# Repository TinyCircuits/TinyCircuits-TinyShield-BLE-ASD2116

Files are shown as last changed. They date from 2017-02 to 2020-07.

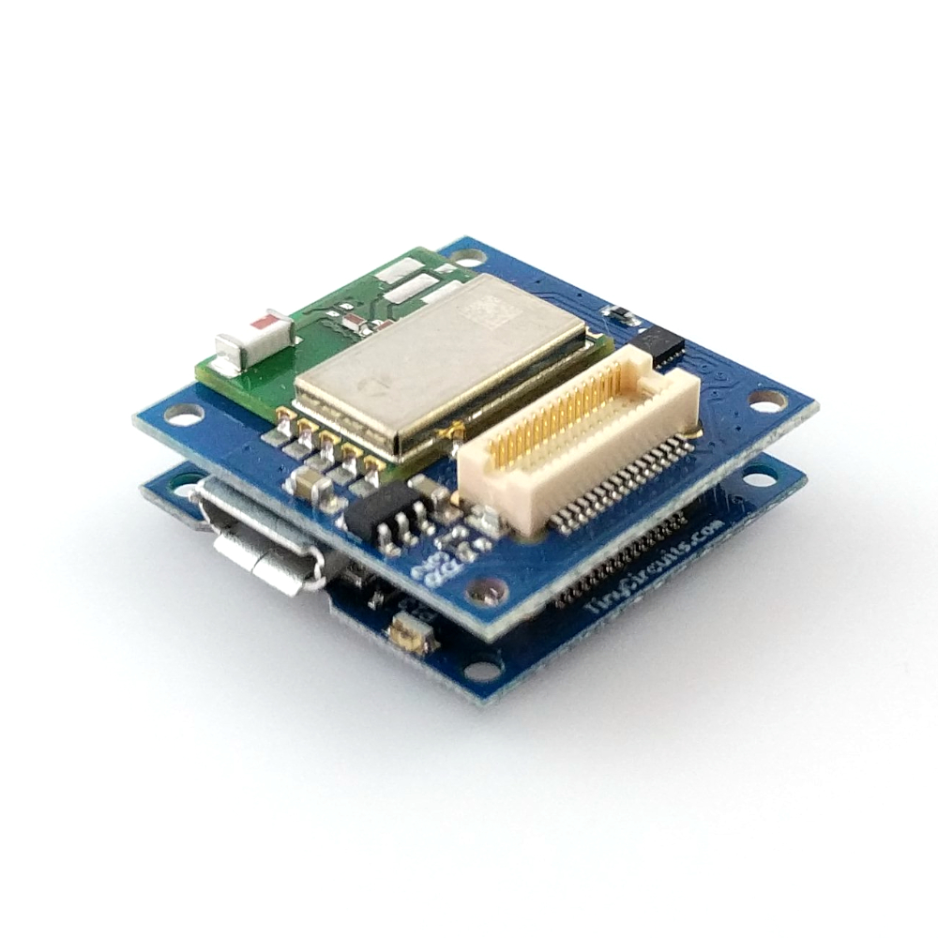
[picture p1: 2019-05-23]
images/ASD2116-R-Tutorial-Image-03.jpg

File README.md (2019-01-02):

# TinyCircuits Bluetooth Low Energy (BLE) TinyShield, ASD2116
# ASD2116 Rev2

The design files are located under design_files/ for the TinyCircuits ASD2116 Rev 2 PCB. This is a TinyShield board that has a BlueNRG-MS module, local power supply and level shifters to connect between the TinyDuino and BLE mod

Format is in Cadsoft Eagle format - Eagle version 6.3 was used for the original design.

For more information on this, check out the product page at TinyCircuits.com: https://tinycircuits.com/collections/communication/products/bluetooth-low-energy-tinyshield

# License

Design by TinyCircuits.
All design files are released under the Creative Commons Attribution Share-Alike 3.0 License, see the following link for details: http://creativecommons.org/licenses/by-sa/3.0

All text above must be included in any redistribution or derived design

This project uses designs and concepts developed as part of the Arduino project and the LilyPad project.  The TinyCircuits design files themselves (schematics, PCB and libraries) are not directly derived from these works' design files and have been created new, however the concepts and basic architecture behind the TinyDuino and TinyLily products are derived and we thank the hard work of the organizations below for their contributions to open-source hardware:
  
Original Arduino Uno Design by Team Arduino

LilyPad Arduino Design by Leah Buechley and Sparkfun Electronics

Please support the open-source hardware community

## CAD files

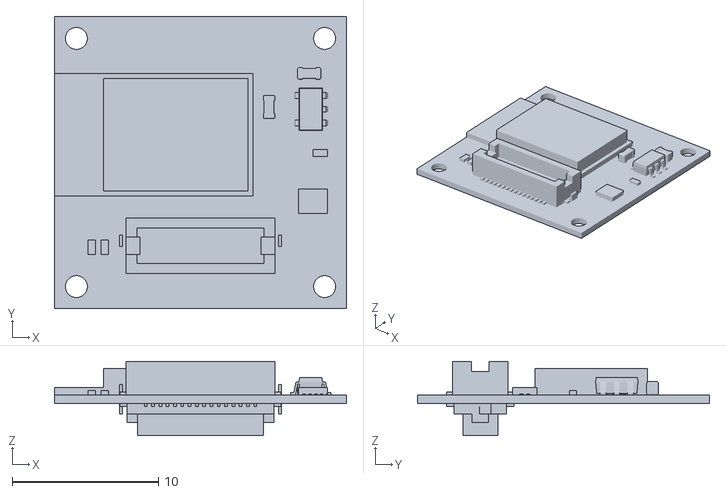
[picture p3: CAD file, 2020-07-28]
cad/TinyShield_STBLE_ASD2116_REV2-STL.stl
20.0 x 20.0 x 5.10

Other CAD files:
cad/TinyShield_STBLE_ASD2116_REV2-DETAILED_DRAWING-DXF.dxf

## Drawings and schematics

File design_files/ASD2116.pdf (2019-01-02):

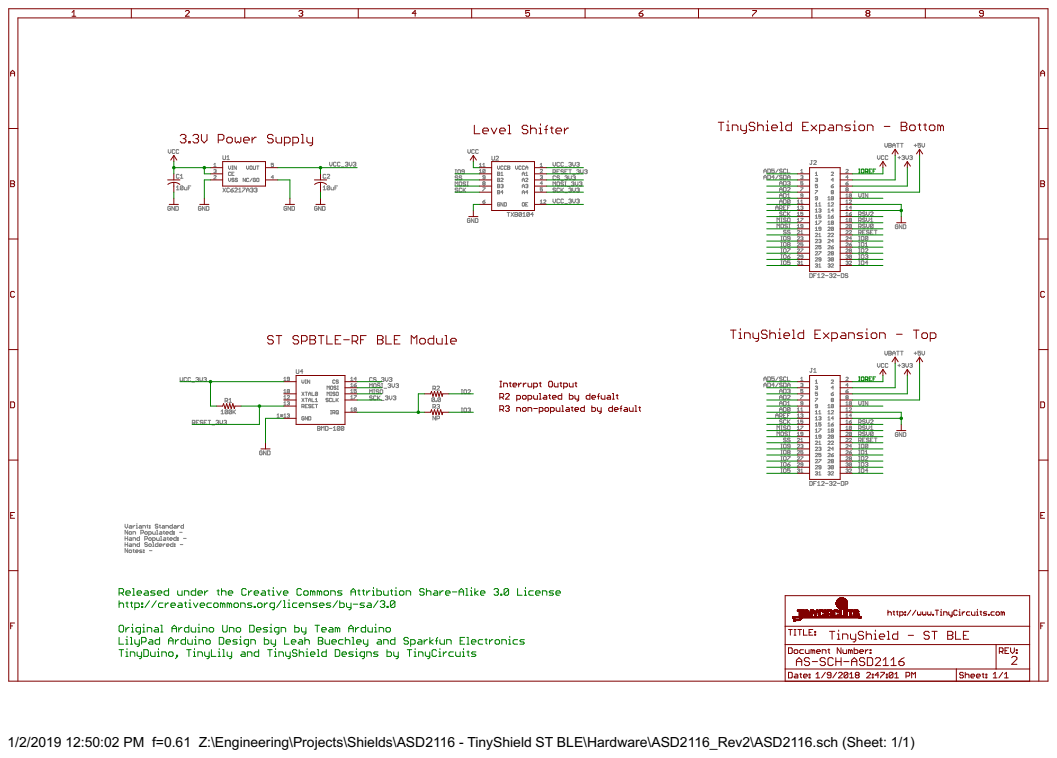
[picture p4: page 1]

1/2/2019 12:50:02 PM f=0.61 Z:\Engineering\Projects\Shields\ASD2116 - TinyShield ST BLE\Hardware\ASD2116_Rev2\ASD2116.sch (Sheet: 1/1)

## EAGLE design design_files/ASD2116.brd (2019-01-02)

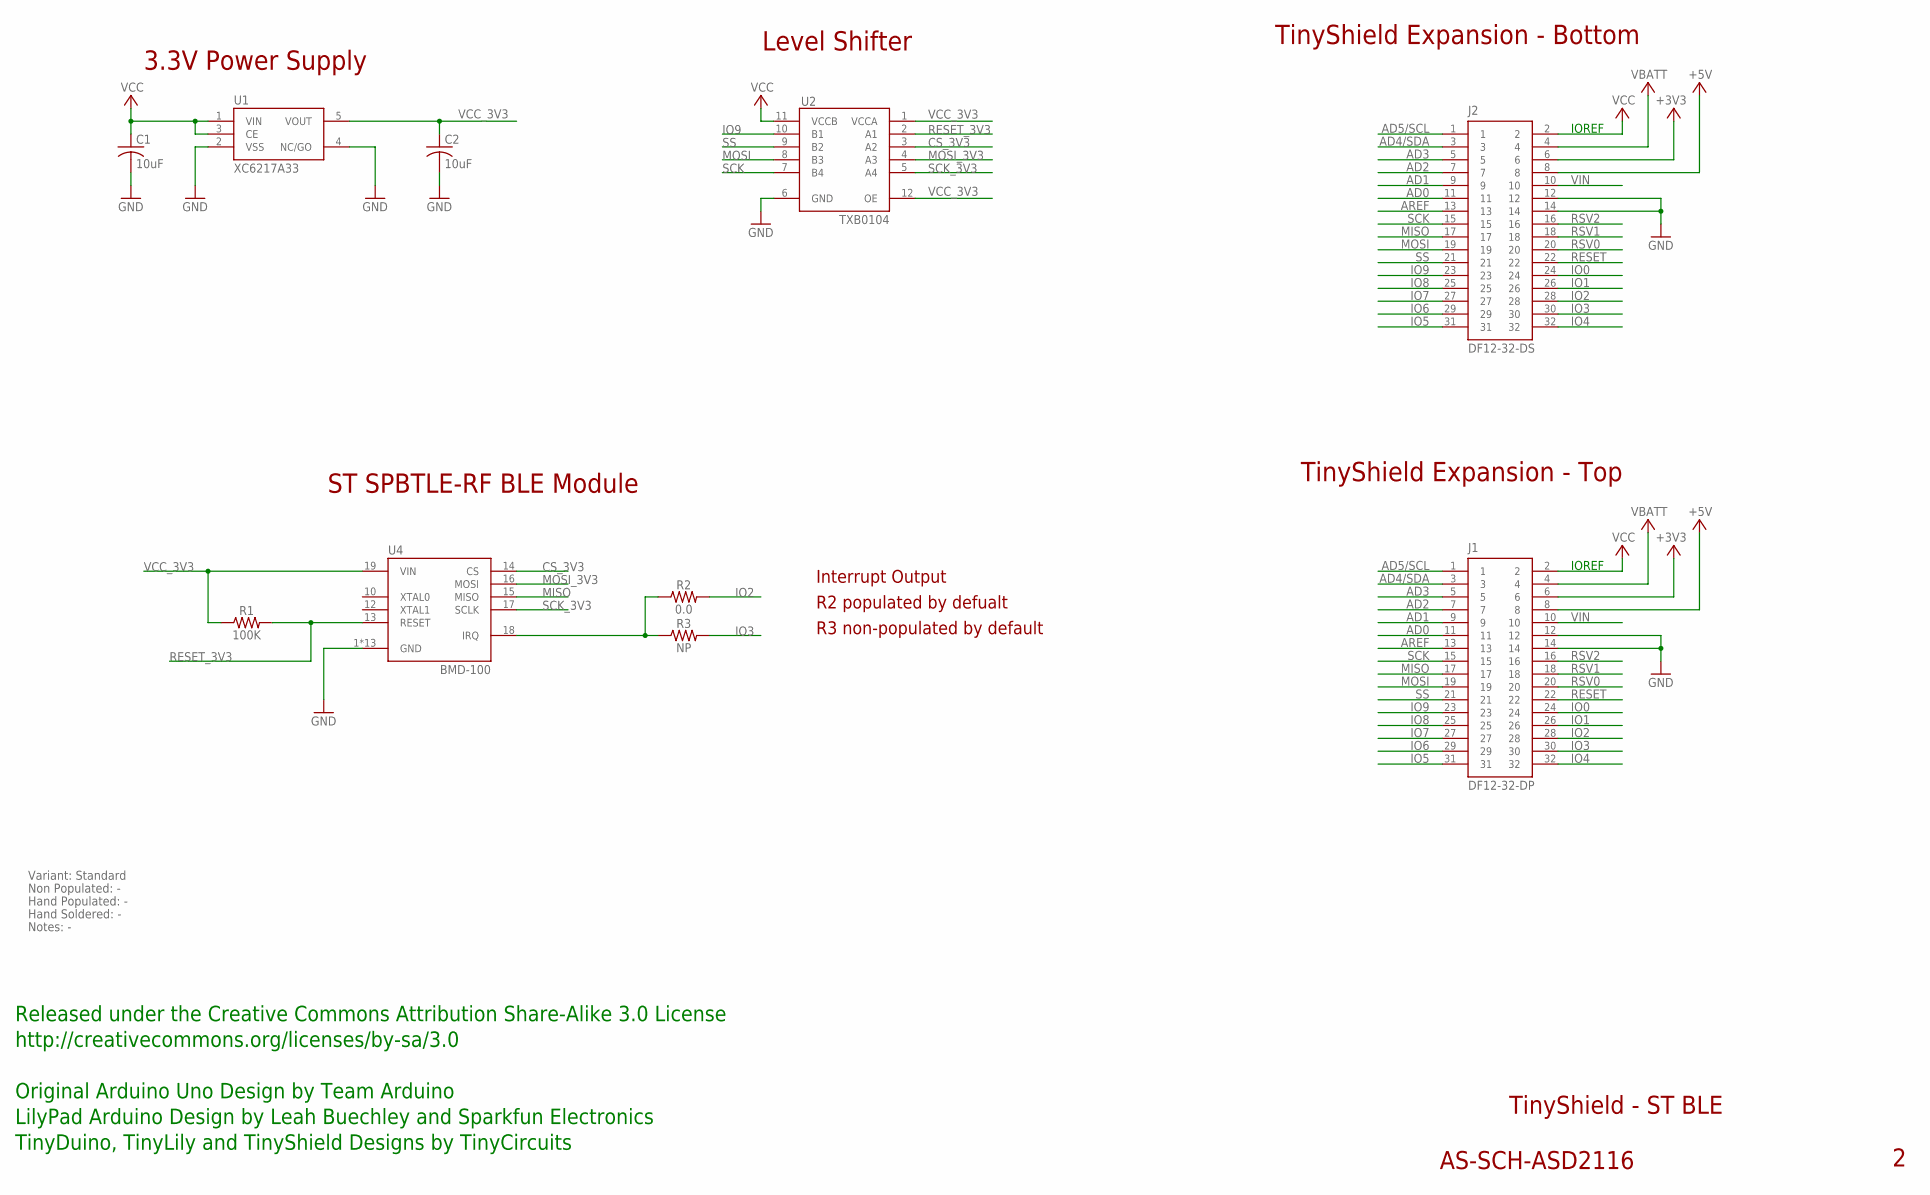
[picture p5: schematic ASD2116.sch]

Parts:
C1, C2: 10uF; C0603; PARTNO AS-ITM-00002
J1: DF12-32-DP; PARTNO AS-ITM-00015
J2: DF12-32-DS; PARTNO AS-ITM-00012
R1: 100K; 0402
R2: 0.0; 0402; PARTNO AS-ITM-00076
R3: NP; 0402; PARTNO AS-ITM-00076
U1: XC6217A33; SOT-25; PARTNO AS-ITM-00249
U2: TXB0104; UQFN-12
U4: BMD-100

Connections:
+3V3: J1.6, J2.6
+5V: J1.8, J2.8
AD0: J1.11, J2.11
AD1: J1.9, J2.9
AD2: J1.7, J2.7
AD3: J1.5, J2.5
AD4/SDA: J1.3, J2.3
AD5/SCL: J1.1, J2.1
AREF: J1.13, J2.13
CS_3V3: U2.3 (A2), U4.14 (CS)
GND: C1.2, C2.2, J1.12, J1.14, J2.12, J2.14, U1.2 (VSS), U1.4 (NC/GO), U2.6 (GND), U4.1 (GND), U4.2 (GND), U4.3 (GND), U4.7 (GND), U4.9 (GND), U4.11 (GND), U4.20 (GND), U4.A (GND), U4.B (GND), U4.C (GND), U4.D (GND), U4.E (GND), U4.F (GND)
IO0: J1.24, J2.24
IO1: J1.26, J2.26
IO2: J1.28, J2.28, R2.2
IO3: J1.30, J2.30, R3.2
IO4: J1.32, J2.32
IO5: J1.31, J2.31
IO6: J1.29, J2.29
IO7: J1.27, J2.27
IO8: J1.25, J2.25
IO9: J1.23, J2.23, U2.10 (B1)
IRQ: R2.1, R3.1, U4.18 (IRQ)
MISO: J1.17, J2.17, U4.15 (MISO)
MOSI: J1.19, J2.19, U2.8 (B3)
MOSI_3V3: U2.4 (A3), U4.16 (MOSI)
RESET: J1.22, J2.22
RESET_3V3: R1.2, U2.2 (A1), U4.13 (RESET)
RSV0: J1.20, J2.20
RSV1: J1.18, J2.18
RSV2: J1.16, J2.16
SCK: J1.15, J2.15, U2.7 (B4)
SCK_3V3: U2.5 (A4), U4.17 (SCLK)
SS: J1.21, J2.21, U2.9 (B2)
VBATT: J1.4, J2.4
VCC: C1.1, J1.2, J2.2, U1.1 (VIN), U1.3 (CE), U2.11 (VCCB)
VCC_3V3: C2.1, R1.1, U1.5 (VOUT), U2.1 (VCCA), U2.12 (OE), U4.19 (VIN)
VIN: J1.10, J2.10

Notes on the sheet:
TinyShield Expansion - Bottom
TinyShield - ST BLE
AS-SCH-ASD2116
TinyShield Expansion - Top
IOREF
Released under the Creative Commons Attribution Share-Alike 3.0 License
http://creativecommons.org/licenses/by-sa/3.0
LilyPad Arduino Design by Leah Buechley and Sparkfun Electronics
TinyDuino, TinyLily and TinyShield Designs by TinyCircuits
Original Arduino Uno Design by Team Arduino
3.3V Power Supply
ST SPBTLE-RF BLE Module
Level Shifter
Interrupt Output
R2 populated by defualt
R3 non-populated by default
Variant: Standard
Non Populated: -
Hand Populated: -
Hand Soldered: -
Notes: -

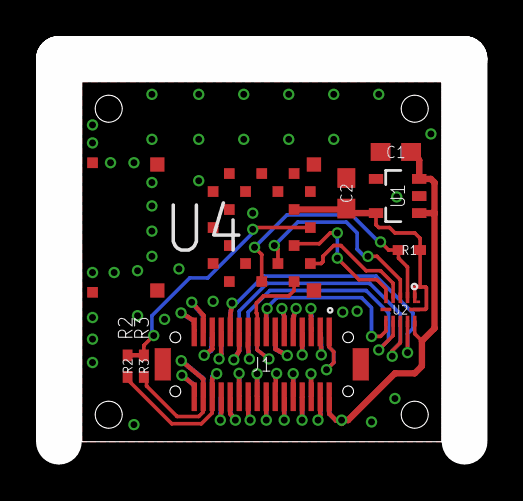
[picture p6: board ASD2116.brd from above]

Board: 2 copper layers, 20.0 x 20.0 mm, 11 parts (1 on the bottom side), 37 nets.

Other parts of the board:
U$1: DOCFIELD-TINYCIRCUITS-PCB

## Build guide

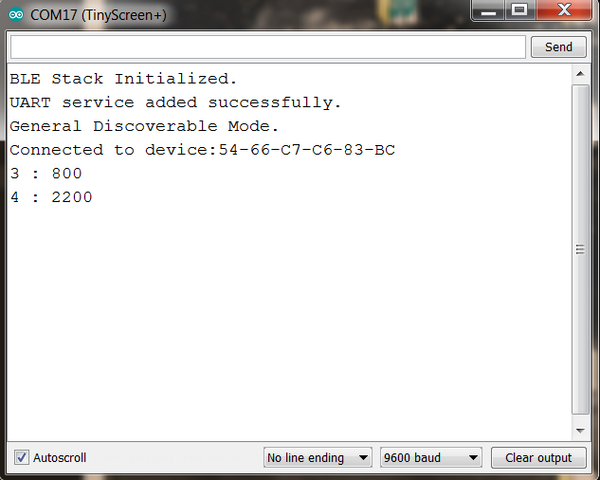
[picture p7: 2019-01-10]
images/ASD2116-Tutorial-Image-15.png

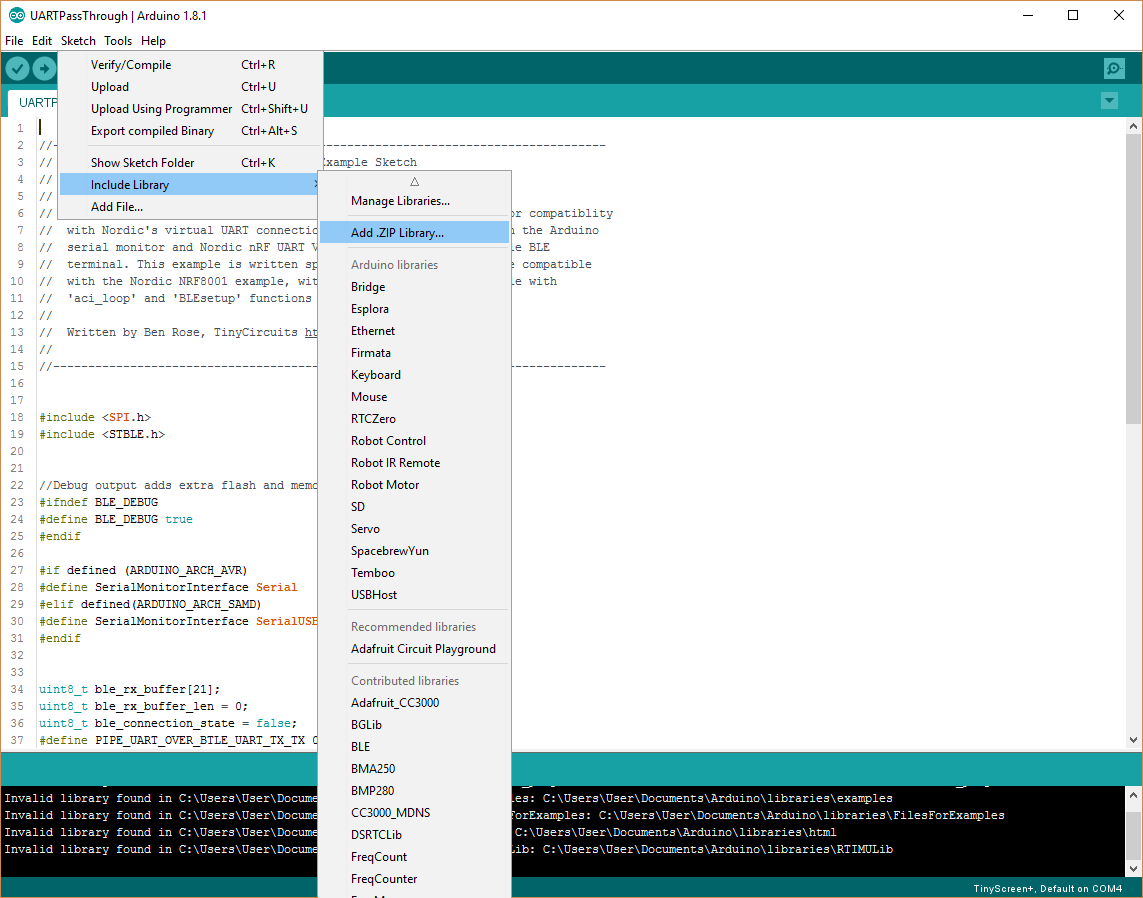
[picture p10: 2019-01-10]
images/ASD2116-Tutorial-Image-04.png

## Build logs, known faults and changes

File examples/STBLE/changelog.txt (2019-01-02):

STBLE 0.1.2, 28 October 2017

* Change HCI_READ_PACKET_NUM_MAX in hci.c from (5) to (2), lowering memory requirements. Does not seem to affect any tested applications.
* Add sm.h to included files

STBLE 0.1.0, 2 March 2016

STMicroelectronics provides BlueNRG-MS code in the X-CUBE-BLE1 software package for the STM32Cube platform. This software is easily portable to the Arduino build environment, which is achieved through the following steps:

1. Copy the files inside hci, includes, utils folders from STM32CubeExpansion_BLE1_V2.8.0/Middlewares/ST/STM32_BlueNRG/SimpleBlueNRG_HCI to STBLE/src/STBlueNRG except for hc_dma_lp.c and bluenrg_utils_small.c

2. Create arduino_bluenrg_ble, arduino_hal files for hardware abstraction following example of STM32 files

3. Create STBLE.h as a general header to include all files and future simplified API

3. Change instances of include brackets (#include <hal.h>) to double quotes (#include "hal.h")

4. In ble_clock.h, ble_list.c:  change #include "bluenrg_itf.h" to #include "../arduino_hal.h"

5. In bluenrg_utils.c, hci.c: change #include "stm32_bluenrg_ble.h" to #include "../arduino_bluenrg_ble.h"

6. Examples are modified into an Arduino-style format compatible with Nordic UART Service for initial release state.

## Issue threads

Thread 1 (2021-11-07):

Unsure of how the GAP commands work.

S0meDev99, 2021-11-07:
Hi there,
I am currently using two TinyZero with the Bluetooth TinyShield and am trying to establish a connection between both devices.
So far I am trying some of the functions with these parameters, in the example UART.ino :
1. ret = aci_gap_start_general_discovery_proc(0x4000, 0x4000,0x00,0x00);
2. ret = aci_gap_create_connection(0x4000, 0x4000, PUBLIC_ADDR, GAP_Peripheral_address, PUBLIC_ADDR, 40, 40, 0, 60, 2000 , 2000);
3. ret = aci_gap_create_connection(0x4000, 0x4000, PUBLIC_ADDR, GAP_Peripheral_address, PUBLIC_ADDR, 40, 40, 0, 60, 2000 , 2000);

The BLEsetup() function is run, followed by only the aci_loop() in the main loop() function. The above mentioned function calls are put inside a separate function and called in the aci_loop().
I checked the status variable return value and it was FF. Am I supposed to run a specific function first before?

In main.ino file
```
void loop() {
  aci_loop();
}
```

aci_loop() in UART.ino
```
void aci_loop() {
  HCI_Process();
  //GAP_Central_Make_Connection();
  GAP_Central_General_Discovery_Procedure();
  GAP_Central_Make_Auto_Connection();
  ble_connection_state = connected;
  if (set_connectable) {
    setConnectable();
    set_connectable = 0;
  }
  if (HCI_Queue_Empty()) {
    //Enter_LP_Sleep_Mode();
  }
}
```

Functions declared in UART.ino
```
void GAP_Central_Make_Connection(void )
{
	tBleStatus ret;
	tBDAddr GAP_Peripheral_address = {0xaa, 0x00, 0x00, 0xE1, 0x80, 0x02};
	ret = aci_gap_create_connection(0x4000, 0x4000, PUBLIC_ADDR, GAP_Peripheral_address, PUBLIC_ADDR, 40, 40, 0, 60, 2000 , 2000);
	if (ret != BLE_STATUS_SUCCESS) PRINTF("Failure.\n")
}

void GAP_Central_General_Discovery_Procedure(void)
{
	tBleStatus ret;
	ret = aci_gap_start_general_discovery_proc(0x4000, 0x4000,0x00,0x00);
	if (ret != BLE_STATUS_SUCCESS) PRINTF("Failure.\n")
}

void GAP_Central_Make_Auto_Connection(void) {
	tBleStatus ret;

 uint8_t addr_array[] = {PUBLIC_ADDR,0xaa, 0x00, 0x00, 0xE1, 0x80, 0x02};
	ret = aci_gap_start_auto_conn_establish_proc_IDB05A1(0x4000,0x4000,PUBLIC_ADDR,40,40,0,60,2000,2000,1,addr_array);
  if (ret != BLE_STATUS_SUCCESS) PRINTF("Failure.\n")
}
```

TinyCircuits, 2021-11-08:
Hello! We do have an example for two ST Bluetooth and TinyZero stacks communicating with each other. We do not have it posted on Github, but we shared it on our forum in this thread: http://forum.tinycircuits.com/index.php?topic=2024.msg4659#msg4659
I believe those examples will be very helpful to you.

You will need to create an account and login in order to be able to access the example programs attached to messages.

S0meDev99, 2021-11-11:
Ok, I see. Thank you very much.

Closed 2021-11-11.

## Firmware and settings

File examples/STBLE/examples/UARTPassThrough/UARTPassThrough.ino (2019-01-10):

/*
  TinyCircuits ST BLE TinyShield UART Example Sketch

  This demo sets up the BlueNRG-MS chipset of the ST BLE module for compatiblity 
  with Nordic's virtual UART connection, and can pass data between the Arduino
  serial monitor and Nordic nRF UART V2.0 app or another compatible BLE
  terminal. This example is written specifically to be fairly code compatible
  with the Nordic NRF8001 example, with a replacement UART.ino file with
  'aci_loop' and 'BLEsetup' functions to allow easy replacement.

  Written 02 March 2016
  By Ben Rose
  Modified 07 January 2019
  By Hunter Hykes

  https://TinyCircuits.com
*/

#include <SPI.h>
#include <STBLE.h>


//Debug output adds extra flash and memory requirements!
#ifndef BLE_DEBUG
#define BLE_DEBUG true
#endif

#if defined (ARDUINO_ARCH_AVR)
#define SerialMonitorInterface Serial
#elif defined(ARDUINO_ARCH_SAMD)
#define SerialMonitorInterface SerialUSB
#endif


uint8_t ble_rx_buffer[21];
uint8_t ble_rx_buffer_len = 0;
uint8_t ble_connection_state = false;
#define PIPE_UART_OVER_BTLE_UART_TX_TX 0

void setup() {
  SerialMonitorInterface.begin(9600);
  while (!SerialMonitorInterface); //This line will block until a serial monitor is opened with TinyScreen+!
  BLEsetup();
}


void loop() {
  aci_loop();//Process any ACI commands or events from the NRF8001- main BLE handler, must run often. Keep main loop short.
  if (ble_rx_buffer_len) {//Check if data is available
    SerialMonitorInterface.print(ble_rx_buffer_len);
    SerialMonitorInterface.print(" : ");
    SerialMonitorInterface.println((char*)ble_rx_buffer);
    ble_rx_buffer_len = 0;//clear afer reading
  }
  if (SerialMonitorInterface.available()) {//Check if serial input is available to send
    delay(10);//should catch input
    uint8_t sendBuffer[21];
    uint8_t sendLength = 0;
    while (SerialMonitorInterface.available() && sendLength < 19) {
      sendBuffer[sendLength] = SerialMonitorInterface.read();
      sendLength++;
    }
    if (SerialMonitorInterface.available()) {
      SerialMonitorInterface.print(F("Input truncated, dropped: "));
      if (SerialMonitorInterface.available()) {
        SerialMonitorInterface.write(SerialMonitorInterface.read());
      }
    }
    sendBuffer[sendLength] = '\0'; //Terminate string
    sendLength++;
    if (!lib_aci_send_data(PIPE_UART_OVER_BTLE_UART_TX_TX, (uint8_t*)sendBuffer, sendLength))
    {
      SerialMonitorInterface.println(F("TX dropped!"));
    }
  }
}

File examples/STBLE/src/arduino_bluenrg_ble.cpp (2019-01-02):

/**
  ******************************************************************************
  * @file    stm32_bluenrg_ble.c
  * @author  CL
  * @version V1.0.0
  * @date    04-July-2014
  * @brief   
  ******************************************************************************
  * @attention
  *
  * <h2><center>&copy; COPYRIGHT(c) 2014 STMicroelectronics</center></h2>
  *
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
  ******************************************************************************
  */ 
  
/* Includes ------------------------------------------------------------------*/

#include <SPI.h>
#include "arduino_bluenrg_ble.h"


#ifdef __cplusplus
extern "C" {
#endif

#include "STBlueNRG/gp_timer.h"
#include "STBlueNRG/debug.h"
#include "STBlueNRG/hci.h"

extern volatile uint32_t ms_counter;

/** @addtogroup BSP
 *  @{
 */

/** @defgroup X-NUCLEO-IDB04A1
 *  @{
 */
 
/** @defgroup STM32_BLUENRG_BLE
 *  @{
 */

/** @defgroup STM32_BLUENRG_BLE_Private_Defines 
 * @{
 */ 

#define HEADER_SIZE 5
#define MAX_BUFFER_SIZE 255
#define TIMEOUT_DURATION 15

/**
 * @}
 */

/** @defgroup STM32_BLUENRG_BLE_Private_Variables
 * @{
 */

SPI_HandleTypeDef SpiHandle;

SPIClass *BLESPI = &SPI;

/**
 * @}
 */

/** @defgroup STM32_BLUENRG_BLE_Private_Function_Prototypes 
 *  @{
 */

/* Private function prototypes -----------------------------------------------*/
static void us150Delay(void);
void set_irq_as_output(void);
void set_irq_as_input(void);

/**
 * @}
 */ 

/** @defgroup STM32_BLUENRG_BLE_Exported_Functions 
 * @{
 */ 

/**
 * @brief  This function is a utility to print the log time
*          in the format HH:MM:SS:MSS (DK GUI time format)
 * @param  None
 * @retval None
 */
void print_csv_time(void){
  uint32_t ms = ms_counter;
  PRINT_CSV("%02d:%02d:%02d.%03d", ms/(60*60*1000)%24, ms/(60*1000)%60, (ms/1000)%60, ms%1000);
}

/**
 * @brief  This function is used for low level initialization of the SPI 
 *         communication with the BlueNRG Expansion Board.
 * @param  hspi: SPI handle.
 * @retval None
 */
void HAL_SPI_MspInit(SPI_HandleTypeDef* hspi)
{
  //
}

/**
 * @brief  Writes data to a serial interface.
 * @param  data1   :  1st buffer
 * @param  data2   :  2nd buffer
 * @param  n_bytes1: number of bytes in 1st buffer
 * @param  n_bytes2: number of bytes in 2nd buffer
 * @retval None
 */
void Hal_Write_Serial(const void* data1, const void* data2, int32_t n_bytes1,
                      int32_t n_bytes2)
{
  struct timer t;
  int ret;
  uint8_t data2_offset = 0;
  
  Timer_Set(&t, CLOCK_SECOND/10);
  
  Disable_SPI_IRQ();
  
  while(1){
    ret = BlueNRG_SPI_Write((uint8_t *)data1,(uint8_t *)data2 + data2_offset, n_bytes1, n_bytes2);
    
    if(ret >= 0){      
      n_bytes1 = 0;
      n_bytes2 -= ret;
      data2_offset += ret;
      if(n_bytes2==0)
        break;
    }
    
    if(Timer_Expired(&t)){
      break;
    }
  }
  
  Enable_SPI_IRQ();
}

/**
 * @brief  Initializes the SPI communication with the BlueNRG
 *         Expansion Board.
 * @param  None
 * @retval None
 */
void BNRG_SPI_Init(void)
{
  pinMode(BNRG_SPI_RESET_PIN,OUTPUT);
  pinMode(BNRG_SPI_CS_PIN,OUTPUT);
  pinMode(BNRG_SPI_EXTI_PIN,INPUT);
  
  BLESPI->begin();
  BLESPI->setDataMode(SPI_MODE0);
  BLESPI->setBitOrder(MSBFIRST);
#if defined(ARDUINO_ARCH_AVR)
  BLESPI->setClockDivider(SPI_CLOCK_DIV8);
  attachInterrupt(0,HCI_Isr,RISING);
#elif defined(ARDUINO_ARCH_SAMD)
  BLESPI->setClockDivider(48);
  attachInterrupt(BNRG_SPI_EXTI_PIN,HCI_Isr,RISING);
#endif

  //__HAL_SPI_ENABLE(&SpiHandle);
}

/**
 * @brief  Resets the BlueNRG.
 * @param  None
 * @retval None
 */
void BlueNRG_RST(void)
{
  HAL_GPIO_WritePin(BNRG_SPI_RESET_PORT, BNRG_SPI_RESET_PIN, GPIO_PIN_SET);
  HAL_Delay(5);
  HAL_GPIO_WritePin(BNRG_SPI_RESET_PORT, BNRG_SPI_RESET_PIN, GPIO_PIN_RESET);
  HAL_Delay(5);
  HAL_GPIO_WritePin(BNRG_SPI_RESET_PORT, BNRG_SPI_RESET_PIN, GPIO_PIN_SET);
  HAL_Delay(5);
}

/**
 * @brief  Reports if the BlueNRG has data for the host micro.
 * @param  None
 * @retval 1 if data are present, 0 otherwise
 */
// FIXME: find a better way to handle this return value (bool type? TRUE and FALSE)
uint8_t BlueNRG_DataPresent(void)
{
  if (HAL_GPIO_ReadPin(BNRG_SPI_EXTI_PORT, BNRG_SPI_EXTI_PIN) == GPIO_PIN_SET)
      return 1;
  else  
      return 0;
} /* end BlueNRG_DataPresent() */

/**
 * @brief  Activate internal bootloader using pin.
 * @param  None
 * @retval None
 */
void BlueNRG_HW_Bootloader(void)
{
  set_irq_as_output();
  BlueNRG_RST();
  set_irq_as_input();
}

/**
 * @brief  Reads from BlueNRG SPI buffer and store data into local buffer.
 * @param  hspi     : SPI handle
 * @param  buffer   : Buffer where data from SPI are stored
 * @param  buff_size: Buffer size
 * @retval int32_t  : Number of read bytes
 */
int32_t BlueNRG_SPI_Read_All(uint8_t *buffer, uint8_t buff_size)
{
  uint16_t byte_count;
  uint8_t len = 0;
  
  const uint8_t header_master[5] = {0x0b, 0x00, 0x00, 0x00, 0x00};
  uint8_t header_slave[5];
  
  //__disable_irq();
  
  HAL_GPIO_WritePin(BNRG_SPI_CS_PORT, BNRG_SPI_CS_PIN, GPIO_PIN_RESET);
  
  /* Read the header */
  HAL_SPI_TransmitReceive_Opt(header_master, header_slave, HEADER_SIZE);
  
  if (header_slave[0] == 0x02) {
    // device is ready
    
    byte_count = (header_slave[4]<<8)|header_slave[3];
    
    if (byte_count > 0) {
      
      // avoid to read more data that size of the buffer
      if (byte_count > buff_size)
        byte_count = buff_size;
      
      HAL_SPI_Receive_Opt(buffer, byte_count);
      
      len = byte_count;
    }    
  }
  
  // Release CS line.
  HAL_GPIO_WritePin(BNRG_SPI_CS_PORT, BNRG_SPI_CS_PIN, GPIO_PIN_SET);
  
  //__enable_irq();
  
#ifdef PRINT_CSV_FORMAT
  if (len > 0) {
    print_csv_time();
    for (int i=0; i<len; i++) {
      PRINT_CSV(" %02x", buffer[i]);
    }
    PRINT_CSV("\n");
  }
#endif  
  
  return len;
}
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

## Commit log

2017-02-21 Rev 1
    Initial commit for the schematics.
    [ASD2116.brd, ASD2116.sch]
2019-01-02 update format
    [ASD2116.brd, ASD2116.sch]
2020-07-28 Add CAD data
    [TinyShield_STBLE_ASD2116_REV2-DETAILED_DRAWING-DXF.dxf, TinyShield_STBLE_ASD2116_REV2-STL.stl]
2020-08-14 Update CAD drawing
    [TinyShield_STBLE_ASD2116_REV2-DETAILED_DRAWING-DXF.dxf]
